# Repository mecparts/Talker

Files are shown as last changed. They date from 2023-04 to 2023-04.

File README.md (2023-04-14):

# General Instrument code to speech board
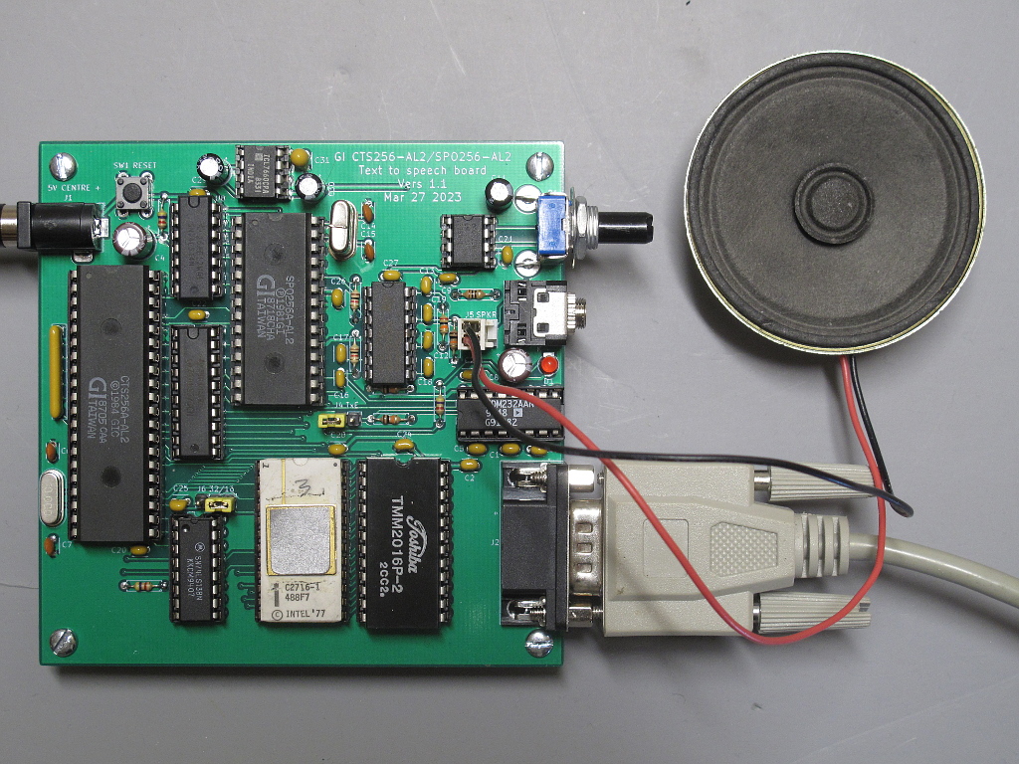
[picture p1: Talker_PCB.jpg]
Talker PCB

<br>

<!--https://user-images.githubusercontent.com/2958269/232146398-3386e22a-f2b2-4650-9bee-b34bc73b3b4c.mp4-->
https://user-images.githubusercontent.com/2958269/232169769-99e8073a-7eef-4b14-9e35-29c342e6777a.mp4

<br>

Quoted from [General Instrument Application Note 0505D: CTS256A-AL2 Code-to-Speech Chipset](https://bitsavers.computerhistory.org/components/gi/speech/General_Instrument_-_AN-0505D_-_CTS256A-AL2_Code-to-Speech_Chipset_-_10Dec1986.pdf)

> ## Description
> 
> The Code-to-Speech chip set consists of two chips: the SPO256A-AL2, an
> allophone-based single chip speech synthesizer, and the CTS256A-AL2, an
> 8-bit microcomputer programmed with a letter-to-sound based algorithm.
> This chip set translates English characters into LPC synthesized speech
> sounds.
> 
> ## SPO256-AL2
> 
> The SPO256-AL2 is General Instruments's standard allophone chip and is
> based on the SPO256A speech synthesizer. This synthesizer consists of a
> 10 or 12 pole second-order cascaded LPC filter, a controller, and a
> 16-bit ROM in which 59 allophones (speech sounds) and five pauses are
> stored.
> 
> ## CTS256A-AL2
> 
> The CRT256A-AL2 is a PIC7041 whose on-board ROM is masked with our
> code-to-speech algorithm. This algorithm converts English text (in the
> form of standard ASCII characters) into SPO256A-AL2 compatible allophone
> addresses, using letter-to-sound rules.

I honestly hadn't expected the level of interest that was shown in this
board when I posted it on [r/electronics](https://reddit.com/r/electronics).
So I hadn't prepared a repository. This effort is therefore a little
rushed, and I beg your forgiveness for any obvious in retrospect errors.

## Schematic

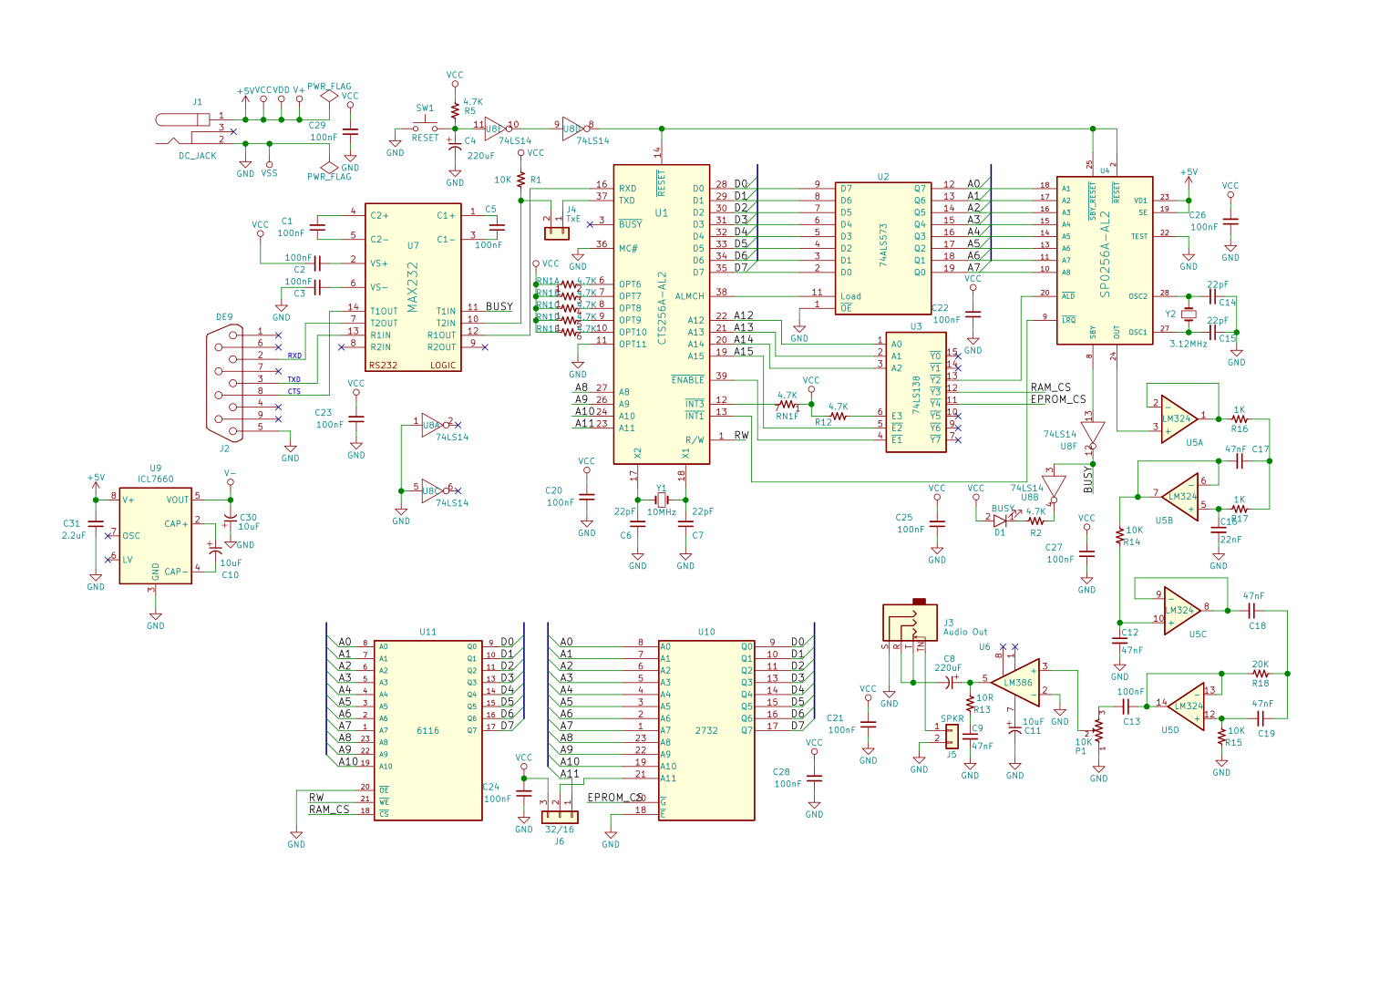
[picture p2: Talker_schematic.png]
Talker schematic


The schematic is based largely on the schematics included in the "Technical
Data" sheets that used to be stapled to the back of the Radio Shack
blister packs. They were also included in the Archer Semiconductor Reference
Guides, specifically the [1988 edition](https://archive.org/details/ArcherSemiconductorReferenceGuide1988).

Those schematics appear to have been based in turn on those included in
the aforementioned GI Application Note.

Since I wasn't expecting anyone else to want to use this, I've customised
the schematic to suit myself. There's no parallel port interface, and the
serial interface is programmed not by onboard DIP switches, but by the
contents of the exception word EPROM.

The active filter was cribbed directly from David C. Alford's article
in the [December 1985 issue of Micro Cornucopia, "Speech Generation With Radio Shack's SPO256"](https://archive.org/details/micro-cornucopia-magazine-1985-12).
Although I seemed to have it working well enough when I breadboarded the
circuit, the first version on the PCB was pretty horrible. It sounded like
it was clipping - a lot. It turned out to be a dumb mistake on my part.
Just because the LM324 is spec'd to work on a single supply, the circuit
wasn't designed for that. Without a negative supply, I was losing the 
entire negative half of the signal. How on earth I didn't hear that on
the breadboarded version, I have no idea. I toyed with the idea of 
pulling V- from the MAX232A and regulating it down to -5V; the current
requirements of the LM324 were modest enough I could have gotten away
with it. But I couldn't quickly find a through hole negative regulator
that didn't draw much more current than the LM324 would have. I had a
few ICL7660s in my parts box, so I went that route instead.

# The PCB

The board layout was inspired by the [CTS256A-AL2 Text-To-Speech Board](https://www.smbaker.com/cts256a-al2-text-to-speech-board).
It wasn't until I saw that one a couple of years back that I realized that
my oh-so-much-larger solderless breadboard version could be tamed into
something more reasonably sized.

In the [gerbers subdirectory](gerbers/), you'll find all the Gerber
files, as well as a zipped compilation suitable for submitting to
[JLCPCB](https://jlcpcb.com/), which is where I had my boards made.

# Parts List

Sch/PCB #|Detail
---------|------
U1|CTS256A-AL2 DIP40 600 mil
U2|74ALS573 DIP20 300 mil
U3|74LS138 DIP16 300 mil
U4|SP0256A-AL2 DIP28 600 mil
U5|LM324 DIP14 300 mil
U6|LM386 DIP8 300 mil
U7|MAX232 DIP16 300 mil
U8|74LS14 DIP14 300 mil
U9|ICL7660 DIP8 300 mil
U10|2716/32 2K/4Kx8 EPROM DIP24 600 mil
U11|6116 2Kx8 SRAM DIP24 600 mil
Y1|10MHz crystal HC49-U
Y2|3.12MHz crystal HC49-U (3.58MHz color burst crytal will work)
R1,R14,<br>R15|10K 1/8W
R13|10 ohms 1/8W
R16,17|1K 1/8W
R18|20K 1/8W
R2,5,12|4.7K 1/8W
RN1|4.7K bussed resistor array (DigiKey# 4607X-101-472LF-ND)
C1,C2,C3,<br>C5,C13,<br>C20-C29|100nF ceramic capcitors, 0.1" lead spacing
C10,C11,C31|10uF electrolytic capacitors, 2mm lead spacing
C16|22nF ceramic capacitor, 0.1" lead spacing
C4,C8|220uF electrolytic capacitors, 2.5mm lead spacing
C6,C7,<br>C14,C15|22pF ceramic capacitors, 2.5mm lead spacing
C9,C12,<br>C17,C18,<br>C19|47nF ceramic capacitors, 2.5mm lead spacing
C31|2.2uF tantalum capacitor, 0.1" lead spacing
D1|3mm LED
J1|DC Barrel 2.1mm Jack
J2|DSUB-9 Female Horizontal (Assmann A-DF 09 A-KG-T2S)
J3|3.5mm audio jack(CUI SJ1-3544)
J4|2 pin header, vertical, 0.1" lead spacing
J5|Molex KK-254 AE-6410-02A 2 pin header, 0.1" lead spacing
J6|3 pin header, vertical, 0.1" lead spacing
P1|10K audio taper pot (Bourns PTV111-1415A-A103)
SW1|SPST 6mm sq. tactile switch (CUI TS02-66-60-BK-100-LCR-D)

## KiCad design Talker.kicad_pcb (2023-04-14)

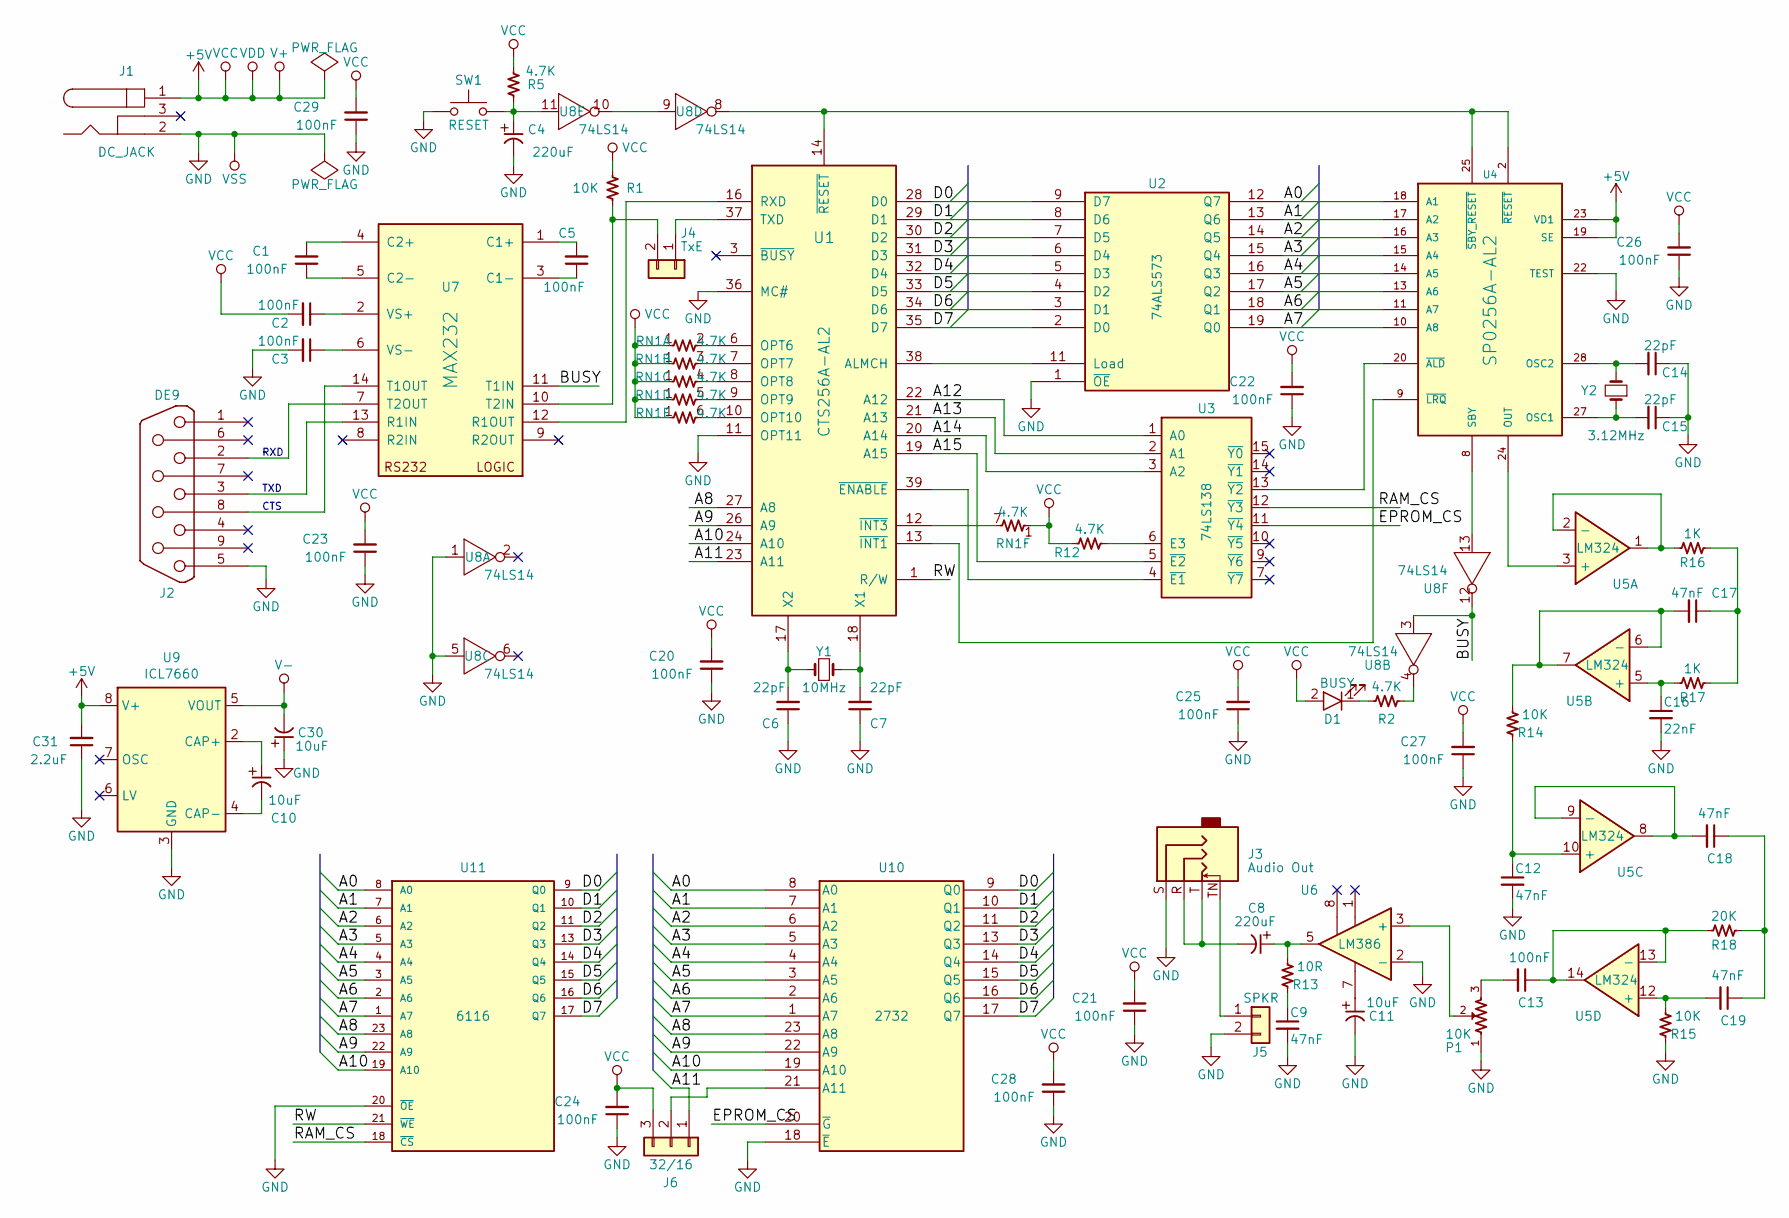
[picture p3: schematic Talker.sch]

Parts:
C1, C2, C3, C5, C13, C20, C21, C22, C23, C24, C25, C26, C27, C28, C29: 100nF; C_Disc_D3_P2.5
C4, C8: 220uF; CP_Radial_D6.3mm_P2.50mm
C6, C7, C14, C15: 22pF; C_Disc_D3_P2.5
C9, C12, C17, C18, C19: 47nF; C_Disc_D3_P2.5
C10, C11, C30: 10uF; CP_Radial_D5.0mm_P2.00mm
C16: 22nF; C_Disc_D3_P2.5
C31: 2.2uF; C_Disc_D3_P2.5
D1: BUSY; LED-3MM
J1: DC_JACK; BarrelJack_Horizontal
J2: DE9; DSUB-9_Female_Horizontal_Assmann_A-DF_09_A-KG-T2S
J3: Audio Out; Jack_3.5mm_CUI_SJ1-3544_Horizontal
J4: TxE; PinHeader_1x02_P2.54mm_Vertical
J5: SPKR; Molex_KK-254_AE-6410-02A_1x02_P2.54mm_Vertical
J6: 32/16; PinHeader_1x03_P2.54mm_Vertical
P1: 10K; Potentiometer_Bourns_PTV111-1_Single_Horizontal
R1, R14, R15: 10K; R3
R2, R5, R12: 4.7K; R3
R13: 10R; R3
R16, R17: 1K; R3
R18: 20K; R3
RN1: 4.7K; R_Array_SIP7
SW1: RESET; SW_PUSH_6mm
U1: CTS256A-AL2; DIP-40_W15.24mm_LongPads
U2: 74ALS573; DIP-20_W7.62mm_LongPads
U3: 74LS138; DIP-16_W7.62mm_LongPads
U4: SP0256A-AL2; DIP-28_W15.24mm_LongPads
U5: LM324; DIP-14_W7.62mm_LongPads
U6: LM386; DIP-8_W7.62mm_LongPads
U7: MAX232; DIP-16_W7.62mm_LongPads
U8: 74LS14; DIP-14_W7.62mm_LongPads
U9: ICL7660; DIP-8_W7.62mm_LongPads
U10: 2732; DIP-24_W15.24mm_LongPads
U11: 6116; DIP-24_W15.24mm_LongPads
Y1: 10MHz; Crystal_HC49-U_Vertical
Y2: 3.12MHz; Crystal_HC49-U_Vertical

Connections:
+5V: C2.2, C20.2, C21.2, C22.2, C23.2, C24.2, C25.2, C26.2, C27.2, C28.2, C29.2, C31.2, D1.2 (A), J1.1, J6.3, R1.1, R5.1, R12.2, RN1.1 (R1.1), U1.25 (VDD), U2.20 (VCC), U3.16 (VCC), U4.7 (VDD), U4.19 (SE), U4.23 (VD1), U5.4 (V+), U6.6 (V+), U7.16 (VCC), U8.14 (VCC), U9.8 (V+), U10.24 (VCC), U11.24 (VCC)
/A0: U2.12 (Q7), U4.18 (A1), U10.8 (A0), U11.8 (A0)
/A1: U2.13 (Q6), U4.17 (A2), U10.7 (A1), U11.7 (A1)
/A2: U2.14 (Q5), U4.16 (A3), U10.6 (A2), U11.6 (A2)
/A3: U2.15 (Q4), U4.15 (A4), U10.5 (A3), U11.5 (A3)
/A4: U2.16 (Q3), U4.14 (A5), U10.4 (A4), U11.4 (A4)
/A5: U2.17 (Q2), U4.13 (A6), U10.3 (A5), U11.3 (A5)
/A6: U2.18 (Q1), U4.11 (A7), U10.2 (A6), U11.2 (A6)
/A7: U2.19 (Q0), U4.10 (A8), U10.1 (A7), U11.1 (A7)
/A8: U1.27 (A8), U10.23 (A8), U11.23 (A8)
/A9: U1.26 (A9), U10.22 (A9), U11.22 (A9)
/A10: U1.24 (A10), U10.19 (A10), U11.19 (A10)
/A11: J6.1, U1.23 (A11)
/A12: U1.22 (A12), U3.1 (A0)
/A13: U1.21 (A13), U3.2 (A1)
/A14: U1.20 (A14), U3.3 (A2)
/A15: U1.19 (A15), U3.5 (~E2)
/BUSY: U7.11 (T1IN), U8.3, U8.12
/D0: U1.28 (D0), U2.9 (D7), U10.9 (Q0), U11.9 (Q0)
/D1: U1.29 (D1), U2.8 (D6), U10.10 (Q1), U11.10 (Q1)
/D2: U1.30 (D2), U2.7 (D5), U10.11 (Q2), U11.11 (Q2)
/D3: U1.31 (D3), U2.6 (D4), U10.13 (Q3), U11.13 (Q3)
/D4: U1.32 (D4), U2.5 (D3), U10.14 (Q4), U11.14 (Q4)
/D5: U1.33 (D5), U2.4 (D2), U10.15 (Q5), U11.15 (Q5)
/D6: U1.34 (D6), U2.3 (D1), U10.16 (Q6), U11.16 (Q6)
/D7: U1.35 (D7), U2.2 (D0), U10.17 (Q7), U11.17 (Q7)
/EPROM_CS: U3.11 (~Y4), U10.20 (~G)
/RAM_CS: U3.12 (~Y3), U11.18 (~CS)
/RW: U1.1 (R/W), U11.21 (~WE)
GND: C3.2, C4.2, C6.1, C7.1, C9.2, C11.2, C12.2, C14.1, C15.1, C16.2, C20.1, C21.1, C22.1, C23.1, C24.1, C25.1, C26.1, C27.1, C28.1, C29.1, C30.1, C31.1, J1.2, J2.5, J3.S, J5.2, P1.1, R15.2, SW1.1, U1.11 (OPT11), U1.36 (MC#), U1.40 (VSS), U2.1 (~OE), U2.10 (GND), U3.8 (GND), U4.1 (VSS), U4.22 (TEST), U6.2 (-), U6.4 (GND), U7.15 (GND), U8.1, U8.5, U8.7 (GND), U9.3 (GND), U10.12 (GND), U10.18 (~E), U11.12 (GND), U11.20 (~OE)
unnamed: C1.1, U7.5 (C2-)
unnamed: C1.2, U7.4 (C2+)
unnamed: C2.1, U7.2 (VS+)
unnamed: C3.1, U7.6 (VS-)
unnamed: C4.1, R5.2, SW1.2, U8.11
unnamed: C5.1, U7.3 (C1-)
unnamed: C5.2, U7.1 (C1+)
unnamed: C6.2, U1.17 (X2), Y1.1
unnamed: C7.2, U1.18 (X1), Y1.2
unnamed: C8.1, R13.1, U6.5
unnamed: C8.2, J3.R, J3.T
unnamed: C9.1, R13.2
unnamed: C10.1, U9.2 (CAP+)
unnamed: C10.2, U9.4 (CAP-)
unnamed: C11.1, U6.7
unnamed: C12.1, R14.2, U5.10 (+)
unnamed: C13.1, R18.2, U5.13 (-), U5.14
unnamed: C13.2, P1.3
unnamed: C14.2, U4.28 (OSC2), Y2.2
unnamed: C15.2, U4.27 (OSC1), Y2.1
unnamed: C16.1, R17.2, U5.5 (+)
unnamed: C17.1, R16.1, R17.1
unnamed: C17.2, R14.1, U5.6 (-), U5.7
unnamed: C18.1, C19.1, R18.1
unnamed: C18.2, U5.8, U5.9 (-)
unnamed: C19.2, R15.1, U5.12 (+)
unnamed: D1.1 (K), R2.2
unnamed: J2.2, U7.7 (T2OUT)
unnamed: J2.3, U7.13 (R1IN)
unnamed: J2.8, U7.14 (T1OUT)
unnamed: J3.TN, J5.1
unnamed: J4.1, U1.37 (TXD)
unnamed: J4.2, R1.2, U7.10 (T2IN)
unnamed: J6.2, U10.21 (A11)
unnamed: P1.2, U6.3 (+)
unnamed: R2.1, U8.4
unnamed: R12.1, U3.6 (E3)
unnamed: R16.2, U5.1, U5.2 (-)
unnamed: RN1.2 (R1.2), U1.6 (OPT6)
unnamed: RN1.3 (R1.2), U1.7 (OPT7)
unnamed: RN1.4 (R1.2), U1.8 (OPT8)
unnamed: RN1.5 (R1.2), U1.9 (OPT9)
unnamed: RN1.6 (R1.2), U1.10 (OPT10)
unnamed: RN1.7 (R1.2), U1.12 (~INT3)
unnamed: U1.13 (~INT1), U4.9 (~LRQ)
unnamed: U1.14 (~RESET), U4.2 (~RESET), U4.25 (~SBY_RESET), U8.8
unnamed: U1.16 (RXD), U7.12 (R1OUT)
unnamed: U1.38 (ALMCH), U2.11 (Load)
unnamed: U1.39 (~ENABLE), U3.4 (~E1)
unnamed: U3.13 (~Y2), U4.20 (~ALD)
unnamed: U4.8 (SBY), U8.13
unnamed: U4.24 (OUT), U5.3 (+)
unnamed: U8.9, U8.10
V-: C30.2, U5.11 (V-), U9.5 (VOUT)

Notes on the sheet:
RXD
TXD
CTS

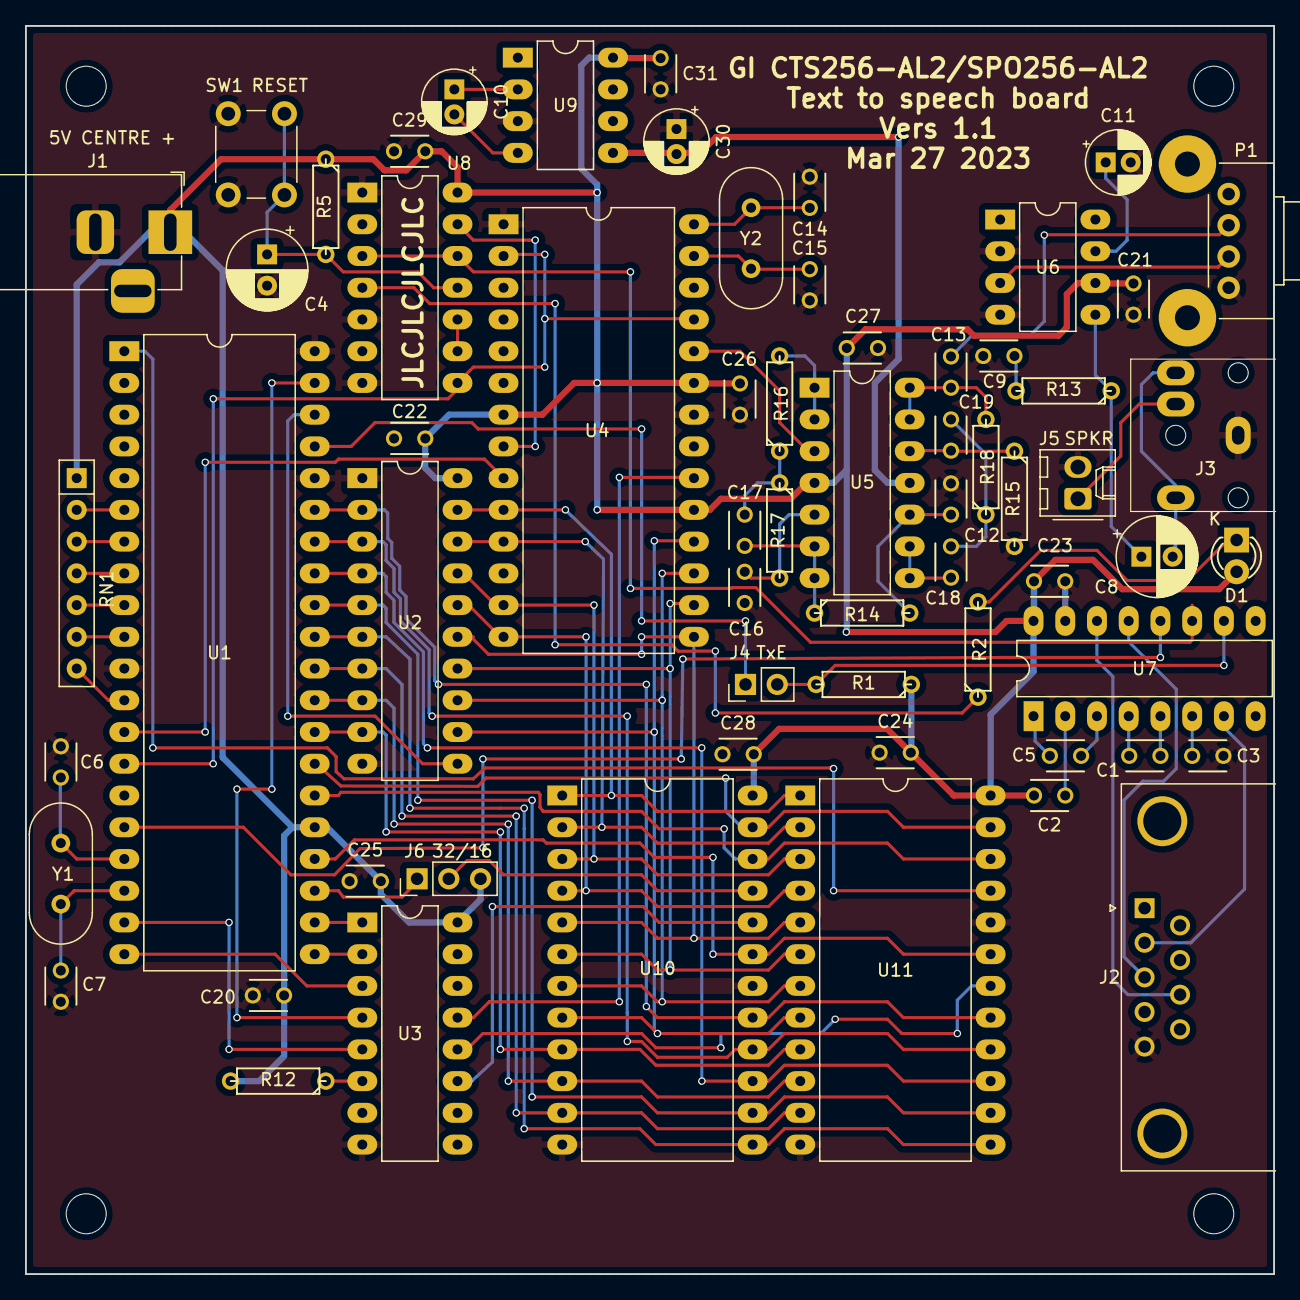
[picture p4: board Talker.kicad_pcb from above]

Board: 2 copper layers, 99.9 x 99.9 mm, 64 parts (0 on the bottom side), 84 nets.

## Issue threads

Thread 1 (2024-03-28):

alternative design for CTS256

lynchaj, 2024-03-28:
Hi
I've had an idea of how to replace the hard to get and expensive CTS256 with a much less expensive alternative using similar, comparable parts (no exotic FPGAs, controllers, etc.)  I would like to contact you but have no email for you and cannot find a way to direct message you on GitHub.  Would you please contact me on GitHub or send me an email at

L Y N C H A J .at. Y A H O O .dot. C O M

Or you can reach me on retro-comp mailing list, retrobrewcomputers.org forum, or retrocomputingforum.com

Thank you!  Andrew Lynch

mecparts, 2024-03-28:
I've been watching your conversation on retro-comp. Just haven't had anything to chime in about.

lynchaj, 2024-03-28:
HiI was wondering if you'd be interested in a CTS256 replacement project?  I am currently working on CTS256/SP0256 project and while studying the datasheets I think I've realized a method to replace the hard to find and expensive CTS256 with a much less expensive and more available alternative.
It is not a redesign using an advanced MCU or FPGA, but rather an off the shelf MCU that's code compatible with the CTS256.  Also, since we already have access to the CTS256 firmware, making updates would be much easier than it is now.
If you're busy or not interested, that is fine.  Since you've already done a lot of work with CTS256/SP0256 I thought I'd offer to you first.
Thanks, Andrew Lynch
    On Thursday, March 28, 2024 at 11:55:51 AM EDT, mecparts ***@***.***> wrote:

I've been watching your conversation on retro-comp. Just haven't had anything to chime in about.

—
Reply to this email directly, view it on GitHub, or unsubscribe.
You are receiving this because you authored the thread.Message ID: ***@***.***>

mecparts, 2024-03-29:
I'm sorry, but what is it that you're asking for? Have you come across a stash of TMS7000s? What do you need me for?

lynchaj, 2024-03-29:
HiJust wondering if you wanted to be part of a small group project to replace the CTS256 with less expensive alternatives. What I am asking you to be on the design, build and test team.  If you're not available or don't have time that's OK.
I've been reviewing the datasheets as part of working on my Voice IO board and realized it would be possible to use other components to accomplish the same thing as a CTS256 except it would be much less expensive and easier to obtain.
My plan is to build a small test board based on the mecparts Talker design and I'll make the modifications.  Since you have experience with CTS256 already I thought you might be interested in pursuing this goal as well.  My plan is to get some test boards made and distribute to a small team (less than 5 people).
Would you please send an email to my yahoo account so we can take the conversation off of GitHub?  All of this is being posted in the Issue I opened (sorry about that, I could not find another way to contact you).
The idea is actually pretty simple and should not involve a lot of heavy-duty development.  Either it will work or not.  I'd like to find out and thought maybe you would also be interested.
Thanks, Andrew Lynch

    On Friday, March 29, 2024 at 12:36:12 PM EDT, mecparts ***@***.***> wrote:

I'm sorry, but what is it that you're asking for? Have you come across a stash of TMS7000s? What do you need me for?

—
Reply to this email directly, view it on GitHub, or unsubscribe.
You are receiving this because you authored the thread.Message ID: ***@***.***>

mecparts, 2024-03-30:
I have so many projects already on the go that I really don't have the time to add another one.

lynchaj, 2024-03-30:
HiOK, thanks for considering it!
Thanks, Andrew Lynch
    On Saturday, March 30, 2024 at 12:26:57 PM EDT, mecparts ***@***.***> wrote:

I have so many projects already on the go that I really don't have the time to add another one.

—
Reply to this email directly, view it on GitHub, or unsubscribe.
You are receiving this because you authored the thread.Message ID: ***@***.***>

lynchaj, 2024-03-30:
Hi,BTW, I am designing a test board based on your mecparts Talker design.  I liked it plus you used KiCAD and all of my other stuff is in KiCAD as well.
I was hoping for a quick modification but in the conversion from the KiCAD version to my KiCAD version 6, introduced a bunch of errors and warnings.  By the time I fixed everything for version 6 to run clean ERC and DRC, I had redone the schematic and the PCB layout.  
Still, I appreciate you making your design available as a starting point even if KiCAD saw to it that it was a complete redo.  Unfortunately, this same thing has happened to me whenever I update an older design.  Even my own.
I think the schematic is basically done and I am cleaning up the PCB layout now.  I am using a 100x160mm Euroboard instead of the 100x100mm format since I have to add some components and want it spread out in case of modifications.
Thanks, Andrew Lynch

    On Saturday, March 30, 2024 at 12:26:57 PM EDT, mecparts ***@***.***> wrote:

I have so many projects already on the go that I really don't have the time to add another one.

—
Reply to this email directly, view it on GitHub, or unsubscribe.
You are receiving this because you authored the thread.Message ID: ***@***.***>

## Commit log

2023-02-19 Added schematic PNG
2023-04-14 Modified the circuit to add a negative supply for the op-amp. It made a world of difference!
    [Talker-B_Cu.gbl, Talker-B_Mask.gbs, Talker-B_Paste.gbp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]
2023-04-14 Updated board image
2023-04-14 Added board image
    (since MP4 video nor thumbnail seems to be working... odd)
2023-04-14 Ironing out the video wrinkle
    Use H264 rather than MPEG-4 and cross fingers
